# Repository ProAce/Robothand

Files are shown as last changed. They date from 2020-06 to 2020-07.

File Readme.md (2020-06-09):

# Robothand

This is the coming together of a project that has been lying on the shelf for 5 years. When a buddy and I had to do a school project to graduate we decided to build a robothand that would wirelessly mimic our own hand movement. This made to be a bit of a far stretch for two inexperienced 16 year olds, but we got pretty far. After deciding that the flex sensors we wanted to use where too expensive (10€ a piece) we found a way to make them ourselves. Eventually we couldn't get it too work wirelessly, but it did work wired... kinda.

Now I figured this was something that had to be finished, and with a little more budget and knowledge this time it is coming together quite nicely.

For testing purposes I used a arduino nano I had lying around as a I2C ADC for the ESP8266 board. The hardware design in this repository utilises an ADC128D818 unit which you could order assembled from services like JLCPCB but is also solderable by hand.

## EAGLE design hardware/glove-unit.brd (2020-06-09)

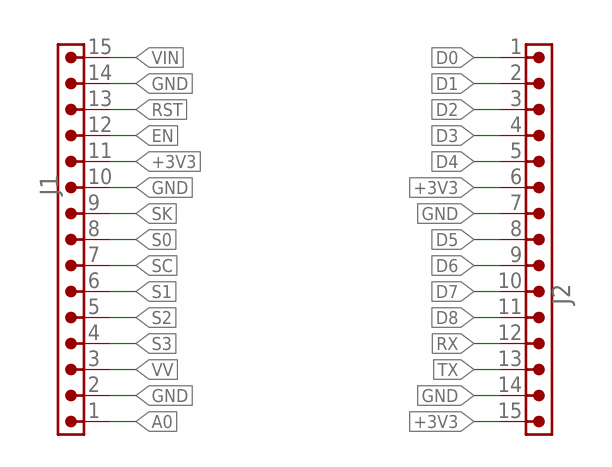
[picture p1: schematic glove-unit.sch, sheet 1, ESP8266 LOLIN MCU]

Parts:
J1, J2: 6130XX11121_61301511121; 61301511121

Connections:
+3V3: J1.11, J2.6, J2.15; also elsewhere on the board
A0: J1.1
D0: J2.1
D1: J2.2; also elsewhere on the board
D2: J2.3; also elsewhere on the board
D3: J2.4
D4: J2.5
D5: J2.8
D6: J2.9
D7: J2.10
D8: J2.11
EN: J1.12
GND: J1.2, J1.10, J1.14, J2.7, J2.14; also elsewhere on the board
RST: J1.13
RX: J2.12
S0: J1.8
S1: J1.6
S2: J1.5
S3: J1.4
SC: J1.7
SK: J1.9
TX: J2.13
VIN: J1.15; also elsewhere on the board
VV: J1.3

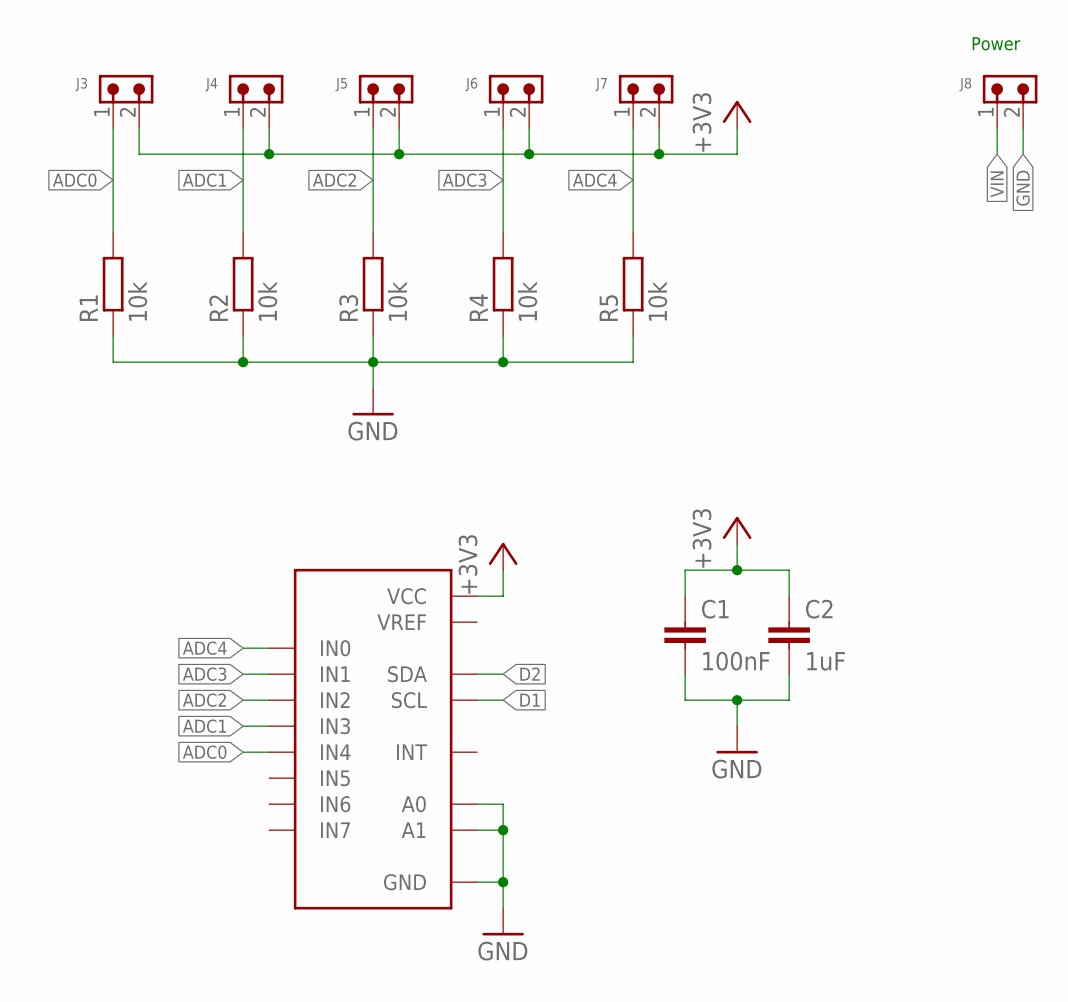
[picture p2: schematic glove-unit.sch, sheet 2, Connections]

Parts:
C1: 100nF; C0603
C2: 1uF; C0603
J3, J4, J5, J6, J7, J8: 6130XX11121_61300211121; 61300211121
R1, R2, R3, R4, R5: 10k; R0805
U$1: ADC128D818; TSSOP-16

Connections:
+3V3: C1.1, C2.1, J3.2, J4.2, J5.2, J6.2, J7.2, U$1.5 (VCC); also elsewhere on the board
ADC0: J3.1, R1.2, U$1.12 (IN4)
ADC1: J4.1, R2.2, U$1.13 (IN3)
ADC2: J5.1, R3.2, U$1.14 (IN2)
ADC3: J6.1, R4.2, U$1.15 (IN1)
ADC4: J7.1, R5.2, U$1.16 (IN0)
D1: U$1.3 (SCL); also elsewhere on the board
D2: U$1.2 (SDA); also elsewhere on the board
GND: C1.2, C2.2, J8.2, R1.1, R2.1, R3.1, R4.1, R5.1, U$1.4 (GND), U$1.7 (A0), U$1.8 (A1); also elsewhere on the board
VIN: J8.1; also elsewhere on the board

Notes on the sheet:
Power

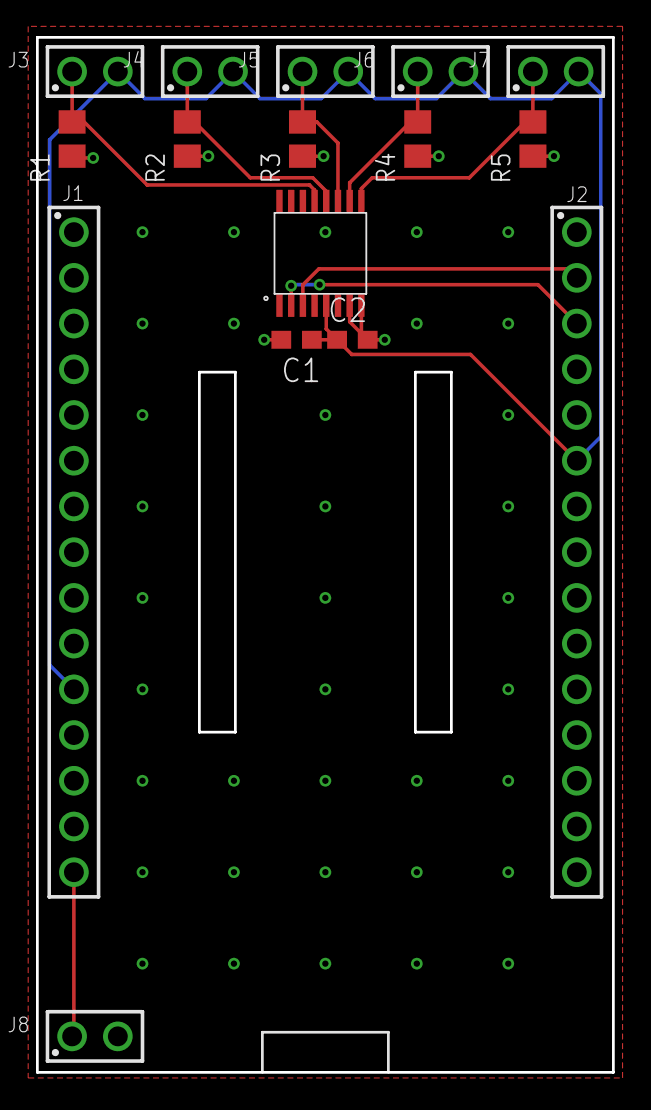
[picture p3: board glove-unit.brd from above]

Board: 2 copper layers, 32.0 x 57.5 mm, 16 parts (0 on the bottom side), 10 nets.

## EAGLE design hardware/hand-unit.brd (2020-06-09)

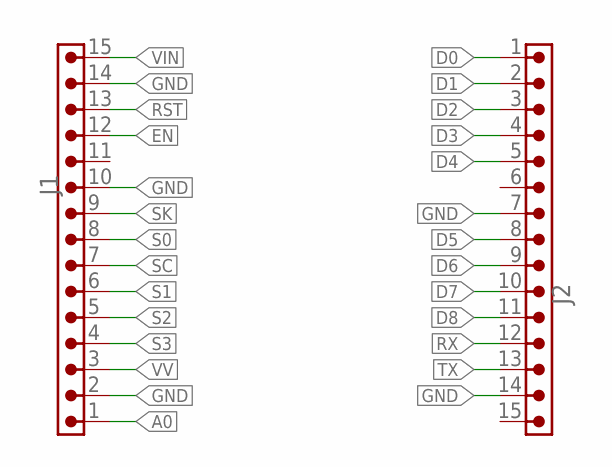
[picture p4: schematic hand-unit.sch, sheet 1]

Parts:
J1, J2: 6130XX11121_61301511121; 61301511121

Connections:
A0: J1.1
D0: J2.1; also elsewhere on the board
D1: J2.2
D2: J2.3; also elsewhere on the board
D3: J2.4
D4: J2.5
D5: J2.8; also elsewhere on the board
D6: J2.9; also elsewhere on the board
D7: J2.10; also elsewhere on the board
D8: J2.11
EN: J1.12
GND: J1.2, J1.10, J1.14, J2.7, J2.14; also elsewhere on the board
RST: J1.13
RX: J2.12
S0: J1.8
S1: J1.6
S2: J1.5
S3: J1.4
SC: J1.7
SK: J1.9
TX: J2.13
VIN: J1.15; also elsewhere on the board
VV: J1.3

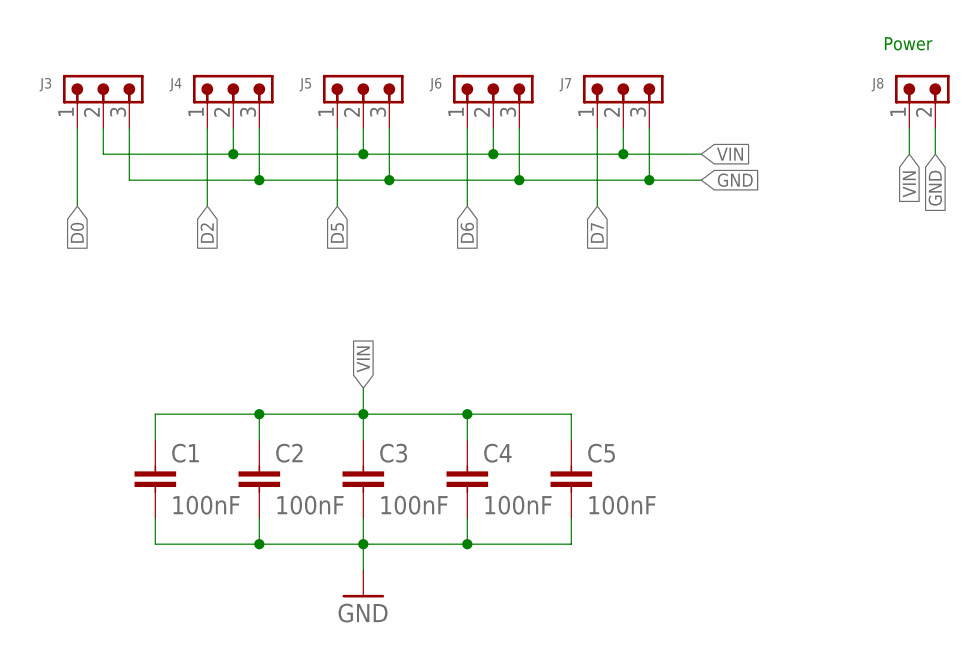
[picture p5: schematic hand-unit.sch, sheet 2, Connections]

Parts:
C1, C2, C3, C4, C5: 100nF; C0603
J3, J4, J5, J6, J7: 6130XX11121_61300311121; 61300311121
J8: 6130XX11121_61300211121; 61300211121

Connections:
D0: J3.1; also elsewhere on the board
D2: J4.1; also elsewhere on the board
D5: J5.1; also elsewhere on the board
D6: J6.1; also elsewhere on the board
D7: J7.1; also elsewhere on the board
GND: C1.2, C2.2, C3.2, C4.2, C5.2, J3.3, J4.3, J5.3, J6.3, J7.3, J8.2; also elsewhere on the board
VIN: C1.1, C2.1, C3.1, C4.1, C5.1, J3.2, J4.2, J5.2, J6.2, J7.2, J8.1; also elsewhere on the board

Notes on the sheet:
Power

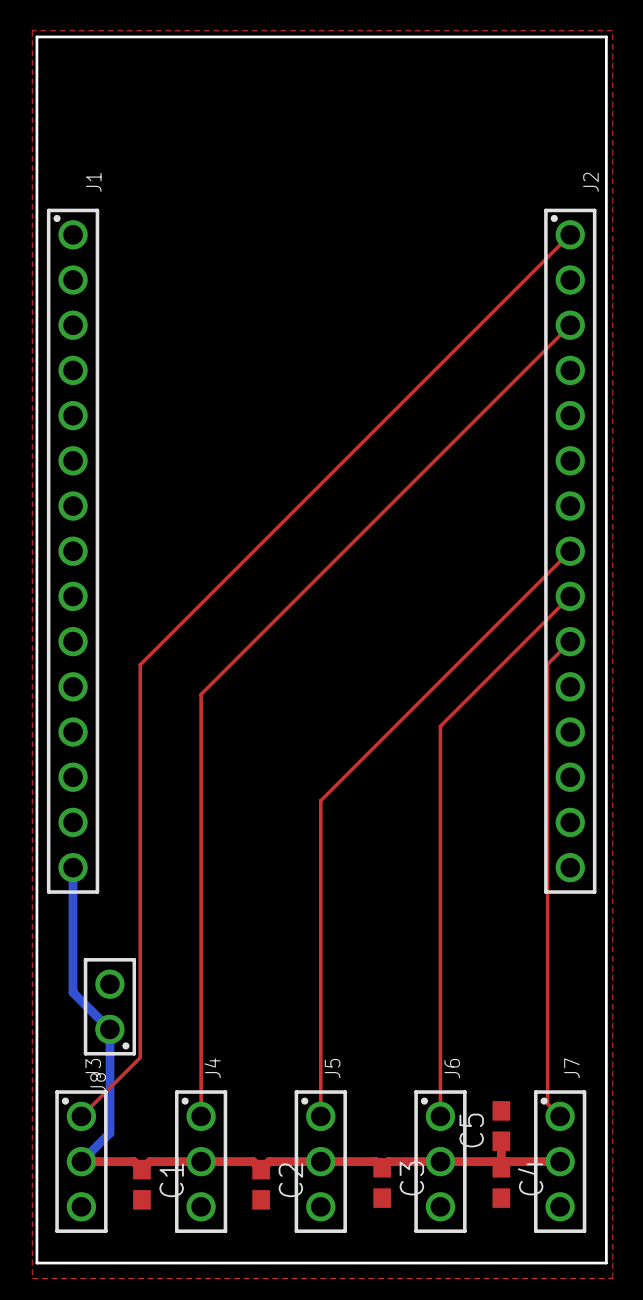
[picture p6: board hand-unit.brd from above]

Board: 2 copper layers, 32.0 x 68.9 mm, 13 parts (0 on the bottom side), 7 nets.

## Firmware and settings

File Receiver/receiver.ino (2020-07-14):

#include <ESP8266WiFi.h>
#include <ESP8266WebServer.h>
#include <ArduinoWebsockets.h>
#include <FS.h>
#include <Servo.h>

char ssid[] = "IoT"; // your network SSID (name)

using namespace websockets;

WebsocketsServer wsServer;
WebsocketsClient client;
ESP8266WebServer server(80);

Servo thumb;
Servo index_finger;
Servo middle_finger;
Servo ring_finger;
Servo pinky;

int finger_positions[5];

void setup()
{
  Serial.begin(115200);

  WiFi.begin(ssid);

  while (WiFi.status() != WL_CONNECTED)
  { // Wait for the Wi-Fi to connect
    delay(250);
  }

  Serial.print("IP address:\t");
  Serial.println(WiFi.localIP()); // Send the IP address of the ESP8266 to the computer

  // start the Websocket server on port 8080.
  wsServer.listen(8080);

  SPIFFS.begin(); // Start the SPI Flash Files System.

  server.onNotFound([]() {                              // If the client requests any URI.
    if (!handle_file_read(server.uri()))                // send it if it exists.
      server.send(404, "text/plain", "404: Not Found"); // otherwise, respond with a 404 (Not Found) error.
  });

  // Start the server on port 80.
  server.begin();

  thumb.attach(16);
  index_finger.attach(4);
  middle_finger.attach(14);
  ring_finger.attach(12);
  pinky.attach(13);
}

void loop()
{
  server.handleClient();

  if (wsServer.poll()) // Check if there is a new client trying to connect.
  {
    Serial.println("New client");
    client = wsServer.accept();

    // Setup Callbacks for the new client.
    client.onMessage(onMessageCallback);
    client.onEvent(onEventsCallback);
  }

  if (client.available()) // If there is a client check if it has new messages.
  {
    client.poll();
  }
}

// Functions to handle websocket messages and events

void onEventsCallback(WebsocketsEvent event, String data)
{
  switch (event)
  {
  case WebsocketsEvent::ConnectionOpened:
    Serial.println("Connnection Opened");
    break;

  case WebsocketsEvent::ConnectionClosed:
    Serial.println("Connnection Closed");
    client.close();
    break;
  }
}

void onMessageCallback(WebsocketsMessage message)
{
  Serial.print("Got Message: ");
  Serial.println(message.data());
  String data = message.data();

  switch (data[0]) // Parse the incoming message.
  {
  case 'f':
    unmarshall_finger_positions(data.substring(2));
    update_finger_positions();
    break;

  case 'i':
    data = marshall_finger_positions();
    client.send(data);
    break;
  }
}

// Functions to handle the webserver file serving

String get_content_type(String filename)
{ // Convert the file extension to the correct MIME type.
  if (filename.endsWith(".html"))
  {
    return "text/html";
  }
  else if (filename.endsWith(".css"))
  {
    return "text/css";
  }
  else if (filename.endsWith(".js"))
  {
    return "application/javascript";
  }
  else if (filename.endsWith(".ico"))
  {
    return "image/x-icon";
  }
  return "text/plain";
}

bool handle_file_read(String path)
{ // Send the correct file to the client (if it exists).
  if (path.endsWith("/"))
  {
    path += "index.html"; // If a folder is requested, send the index file.
  }

  String contentType = get_content_type(path); // Get the MIME type.

  if (SPIFFS.exists(path))
  {                                                     // If the file exists.
    File file = SPIFFS.open(path, "r");                 // Open it.
    size_t sent = server.streamFile(file, contentType); // And send it to the client.
    file.close();                                       // Then close the file again.
    return true;
  }

  return false; // If the file doesn't exist, return false.
}

void unmarshall_finger_positions(String message)
{
  uint8_t index = 0;
  uint8_t next_index = message.indexOf(",");

  finger_positions[0] = message.substring(index, next_index).toInt();

  index = next_index + 1;
  next_index = message.indexOf(",", index);

  finger_positions[1] = message.substring(index, next_index).toInt();

  index = next_index + 1;
  next_index = message.indexOf(",", index);

  finger_positions[2] = message.substring(index, next_index).toInt();

  index = next_index + 1;
  next_index = message.indexOf(",", index);

  finger_positions[3] = message.substring(index, next_index).toInt();

  finger_positions[4] = message.substring(next_index + 1).toInt();
}

String marshall_finger_positions()
{
  String data = "f,";

  data += finger_positions[0];
  data += ",";
  data += finger_positions[1];
  data += ",";
  data += finger_positions[2];
  data += ",";
  data += finger_positions[3];
  data += ",";
  data += finger_positions[4];

  return data;
}

void update_finger_positions(void)
{
  thumb.write(adc_to_rotation(finger_positions[0], 80, 180));
  index_finger.write(adc_to_rotation(finger_positions[1], 60, 180));
  middle_finger.write(adc_to_rotation(finger_positions[2], 60, 180));
  ring_finger.write(adc_to_rotation(finger_positions[3], 60, 180));
  pinky.write(adc_to_rotation(finger_positions[4], 60, 180));
}

int adc_to_rotation(int value, int min, int max)
{
  return value * (max - min) / 4095.00 + min; // 4095 is the maximum ADC value.
}

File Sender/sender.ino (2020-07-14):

#include <ESP8266WiFi.h>
#include <ArduinoWebsockets.h>
#include <Wire.h>
#include <ADC128D818.h>

const char *ssid = "IoT"; // The SSID (name) of the Wi-Fi network you want to connect to
const char *websockets_server = "ws://192.168.2.22:8080";

using namespace websockets;

WebsocketsClient client;

ADC128 adc(0x1D);

void setup()
{
    Serial.begin(115200);

    WiFi.begin(ssid); // Connect to the network
    Serial.print("Connecting to ");
    Serial.println(ssid);

    while (WiFi.status() != WL_CONNECTED)
    { // Wait for the Wi-Fi to connect
        delay(250);
    }

    Serial.println();
    Serial.println(WiFi.localIP());

    Wire.begin();
    adc.reset();

    ADC128_advanced_configuration advanced_configuration;
    advanced_configuration.selected_mode = 1;

    adc.write_advanced_configuration(advanced_configuration);

    ADC128_channels disabled_channels; // A channel which is true is disabled
    disabled_channels.channel_0 = true;
    disabled_channels.channel_1 = true;
    disabled_channels.channel_2 = true;

    adc.write_disabled_channels(disabled_channels);

    adc.set_conversion_rate(CONTINUOUS);
    adc.start();

    // Connect to server
    client.connect(websockets_server);
}

void loop()
{
    String data = marshall_message();

    client.send(data);
}

String marshall_message()
{
    String data = "f,";

    data += adc.read_ADC_channel(7);
    data += ",";
    data += adc.read_ADC_channel(6);
    data += ",";
    data += adc.read_ADC_channel(5);
    data += ",";
    data += adc.read_ADC_channel(4);
    data += ",";
    data += adc.read_ADC_channel(3);

    return data;
}

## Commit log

2020-06-01 add hardware
    [glove-unit.brd, glove-unit.sch, hand-unit.brd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]
2020-07-14 remove adc hack

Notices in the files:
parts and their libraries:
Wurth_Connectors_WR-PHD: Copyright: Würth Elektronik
